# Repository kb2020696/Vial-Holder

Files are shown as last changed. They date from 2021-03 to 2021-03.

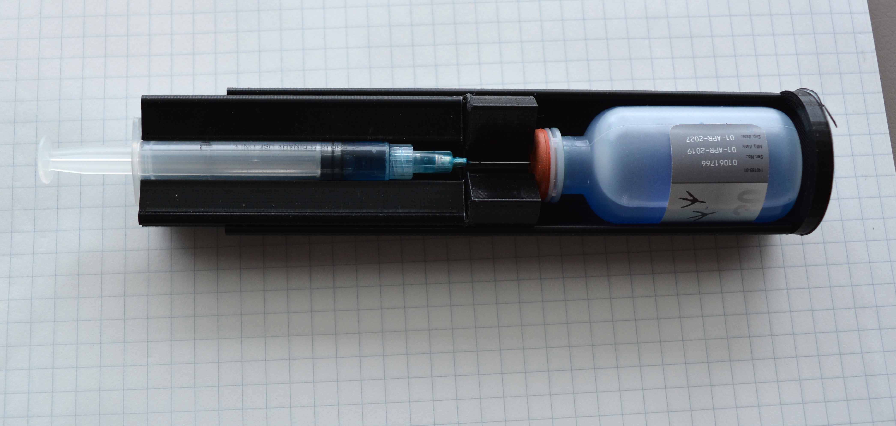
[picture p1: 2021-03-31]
vial holder mod.jpg

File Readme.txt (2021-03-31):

IMPORTANT  - READ THIS FIRST

These files are copyright of LM Designs and may be freely distributed to, and the devices manufactured by, any person who agrees to the following conditions:
1. That any device produced is given freely to any medical professional that requires it with the exception that private individuals may ask for a small charge to cover the actual cost of the materials used.
2. Should any profit be made from the manufacture that it be donated to a charity that supports the families of front line personnel of any type. 

The files provided are AMF (Additive Manufacturing Format) and FCStd (FreeCAD) that enable the device to be printed on any 3D printer after conversion to machine specific code by a suitable slicer such as CURA or the derivative provided by the machine manufacturer.

Since it is likely that the specific dimensions of the device will not be suitable for all situations the actual CAD drawings are made available so that individuals and/or organisations may adapt it to their purposes. In this case the same conditions apply that this is not for profit and any money generated be donated to charity. The original files and the AMF files were generated using FreeCAD. Anyone using these is encouraged to support the organisation (www.freecadweb.org) by making a donation.

THESE FILES ARE PROVIDED BY THE COPYRIGHT HOLDERS "AS IS" AND ANY EXPRESS OR IMPLIED WARRANTIES, INCLUDING, BUT NOT LIMITED TO, THE IMPLIED WARRANTIES OF MERCHANTABILITY AND FITNESS FOR A PARTICULAR PURPOSE ARE DISCLAIMED. IN NO EVENT SHALL THE COPYRIGHT HOLDER OR CONTRIBUTORS BE LIABLE FOR ANY DIRECT, INDIRECT, INCIDENTAL, SPECIAL, EXEMPLARY, OR CONSEQUENTIAL DAMAGES (INCLUDING, BUT NOT LIMITED TO, PROCUREMENT OF SUBSTITUTE GOODS OR SERVICES; LOSS OF USE, DATA, OR PROFITS; OR BUSINESS INTERRUPTION) HOWEVER CAUSED AND ON ANY THEORY OF LIABILITY, WHETHER IN CONTRACT, STRICT LIABILITY, OR TORT (INCLUDING NEGLIGENCE OR OTHERWISE) ARISING IN ANY WAY OUT OF THE USE OF THIS SOFTWARE, EVEN IF ADVISED OF THE POSSIBILITY OF SUCH DAMAGE.

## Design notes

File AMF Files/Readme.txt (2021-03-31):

IMPORTANT  - READ THIS FIRST

These files are copyright of LM Designs and may be freely distributed to, and the devices manufactured by, any person who agrees to the following conditions:
1. That any device produced is given freely to any medical professional that requires it with the exception that private individuals may ask for a small charge to cover the actual cost of the materials used.
2. Should any profit be made from the manufacture that it be donated to a charity that supports the families of front line personnel of any type. 

The files provided are AMF (Additive Manufacturing Format) that enable the device to be printed on any 3D printer after conversion to machine specific code by a suitable slicer such as CURA or the derivative provided by the machine manufacturer.

Since it is likely that the specific dimensions of the device will not be suitable for all situations the actual CAD drawings are be made available so that individuals and/or organisations may adapt it to their purposes. In this case the same conditions apply that this is not for profit and any money generated be donated to charity. The original files and the AMF files were generated using FreeCAD. Anyone using these is encouraged to support the organisation (www.freecadweb.org) by making a donation.

THESE FILES ARE PROVIDED BY THE COPYRIGHT HOLDERS "AS IS" AND ANY EXPRESS OR IMPLIED WARRANTIES, INCLUDING, BUT NOT LIMITED TO, THE IMPLIED WARRANTIES OF MERCHANTABILITY AND FITNESS FOR A PARTICULAR PURPOSE ARE DISCLAIMED. IN NO EVENT SHALL THE COPYRIGHT HOLDER OR CONTRIBUTORS BE LIABLE FOR ANY DIRECT, INDIRECT, INCIDENTAL, SPECIAL, EXEMPLARY, OR CONSEQUENTIAL DAMAGES (INCLUDING, BUT NOT LIMITED TO, PROCUREMENT OF SUBSTITUTE GOODS OR SERVICES; LOSS OF USE, DATA, OR PROFITS; OR BUSINESS INTERRUPTION) HOWEVER CAUSED AND ON ANY THEORY OF LIABILITY, WHETHER IN CONTRACT, STRICT LIABILITY, OR TORT (INCLUDING NEGLIGENCE OR OTHERWISE) ARISING IN ANY WAY OUT OF THE USE OF THIS SOFTWARE, EVEN IF ADVISED OF THE POSSIBILITY OF SUCH DAMAGE.  

Each part of the 8 parts of this device will automatically be printed with the part number. 
The design is intended for use with 3ml or 1ml syringes and vials of 22mm diameter or larger.
The design is easy to modify to use different syringes, vials and needle types with access to the original CAD files. 

Suggested printing instructions

1. This is optimised to print on an extrusion printer. Alterations may be necessary to print on a resin printer.
2. Material:-  This is easiest to print using PLA. The colour of the material is up to the printer or the final user.
3. Print quality:- Since this is intended to be multi-use but essentially disposable if enough are available. The print quality may be lowered to improve printing speed.
4. Slicer settings:- Using PLA on a non glass bed all the parts can be printed wihout brims, platforms or supports. The body, slider and reducer may require a brim depending on the bed and/or machine. All the other parts can be printed without adhesion brims or platforms or supports. Using a glass bed the body, slider and reducer  will require a brim.
5. The following slicer settings are suggested:  Wall thickness 1.5 to 2mm. Interior fill –default (usually 15%) for all parts except the body (#001) and the reducer (#008). These two items are very thin and require a 100% fill. You will require to change the fill % in the advanced or expert settings in the slicer to do this.

Files provided

There are 10 files provided in ZIP file.
Download the ZIP file and extract the files. 

Readme.txt – Contains these instructions
Details.pdf – Contains a detailed description and diagram of the parts. It also gives instruction of how to use the device.

The remaining files are in Additive Manufacturing Format (AMF) to make the 3D printing process machine and slicer independent.
The AMF files:-
Body -001 – main body
Slider -002 – slide section
Spacer -003 to Spacer -006 – Spacer parts of different thicknesses
Pad -007  - Vial location pad – specific to 22mm diameter vial
Reducer -008 – Reducer sleeve to allow the device to be used with 1ml syringes.

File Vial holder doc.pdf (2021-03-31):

Vial holder – functional description

This item consists of 8 separate parts that are assembled to form a complete unit. There is no contact between any part of the unit and the vial contents. Nor should it contact the syringe needles if correctly used. (See the attached diagram).

Part#001 – Outer body. Consists of a platform with a recess to locate a vial and the outer body that holds all the remaining parts in place. The maximum size of vial that can be used is 32mm. Smaller vials can be used with the addition of the vial pad (Part #007)which fits into the main body and is designed to ensure that the vial is centered down the axis of the holder.
Part #002 – Slider. This locates in the main body and is retained in place by protrusions on the body that fit into recesses in the slider. The slider has a longitudinal recess that locates the syringe. The maximum size of syringe that can be used is 3 ml. This is controlled by the size of the recess. With the addition of a reducer sleeve (Part #008) the size of syringe may be reduced.
Parts #003 to #006 – Spacers. These are used in combination to adjust the distance from the outer end of the slider to the cap of the vial being used. In this way the length of needle protruding from the final spacer can be controlled. The ideal is that the needle protrudes far enough only to pierce through the vial cap making removal of the entire contents of the vial simpler.
Part #007 – Vial pad. This item fits inside the main body. Its purpose is to make the center line of the vial line up exactly with the axis of the holder. The thickness of this item controls the exact position of the vial and can be changed by design without affecting the function of the holder.
Part #008 – Reducer sleeve. This reduces the size of the syringe recess to accommodate 1 ml syringe. The internal dimension of this can be changed by design.

How to use this item
This is intended to be held in the hand with the vial at the upper end during normal use.

Section 1 Basic description
1. Ensure that all the parts of the unit are present (see the attached diagram) These are:-
a. Outer body - #001
b. Syringe holder section - #002
c. Spacer parts 3mm #003, 6mm #004, 12mm #005, 18 mm #006
d. Vial pad – #007
e. Reducer sleeve - #008
2. Check that the vial fits into the vial pad. The pad provided is for a standard vial of the type used for a 22mm vial. The device can be used without the pad if necessary.
3. Insert the vial pad into the outer body and slide to the blank end. This is intentionally a tight fit.
4. Take a syringe/needle combination of the type intended to be used for the reconstitution/ dispensing /injections of the vaccine.
5. Slide the assembled syringe into the holder until the finger wings rest on the end of the holder.
6. Remove the needle cover from the syringe and from the side place it into the slot in the syringe holder section.
The following steps (7 through 11) to determine the size of the spacer block need to be done only once assuming the same syringe needle combination is used for all injections.
7. Carefully select which of the spacers will give about 1/4” of needle exposure when placed in contact with the holder. This can be done by inserting the spacer into the outer body of the main assembly from the end. It is retained by the edges of the body.
8. Slide the syringe holder into the body until the spacer contacts the vial pad. At this point the length of the needle protruding from the spacer can be judged. The intention is to have 3/16” to 1/4” of the needle tip exposed. The length of the spacer or a combination of the spacers can used used to get the correct needle tip exposure.
9. Check that the needle is located along the center line of the holder unit. This is to ensure that the needle goes through the center of the vial stopper which is the thinnest part.
10. Slide the syringe holder combination away from the end of the body section until the outer end of the slider is flush with the end of the body.
11. Slide the syringe back in the holder until the needle tip is about 1/2” inside the syringe holder recess.
12. Drop the needle cover into the syringe recess.
13. Slide the syringe forward carefully until the needle is inside the cover.
14. Remove the syringe from the recess and ensure that the needle cover is correctly fitted. Assuming that aseptic precautions have been observed this syringe may be used to reconstitute the vaccine.
15. Remove the crimp from a vial of vaccine and place the vial onto the vial pad.
16. Slide the syringe holder slider section in until the vial is held in place by the spacer block.
17. The holder is now ready for use.

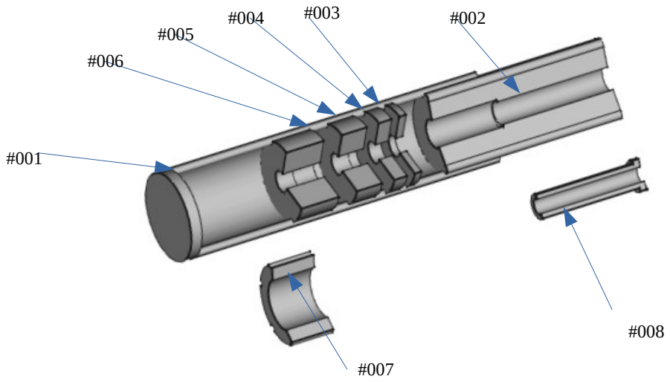
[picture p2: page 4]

#001

#002 #003 #004

#005

#006

#007

#008

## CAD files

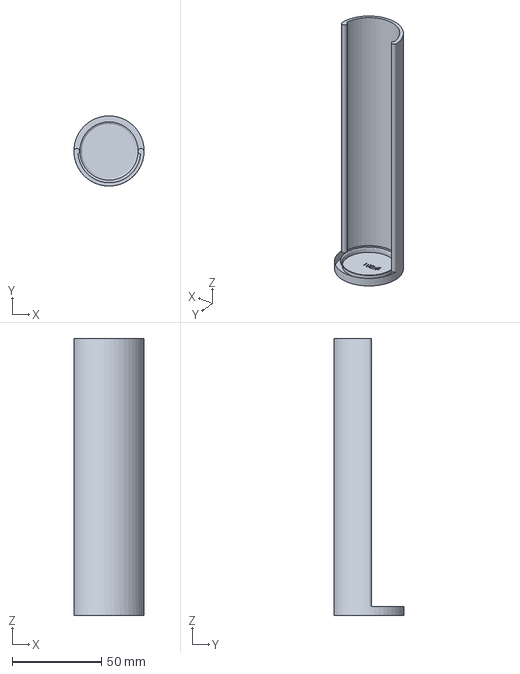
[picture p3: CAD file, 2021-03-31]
AMF Files/Body -001.amf
39.3 x 39.3 x 155.0 mm

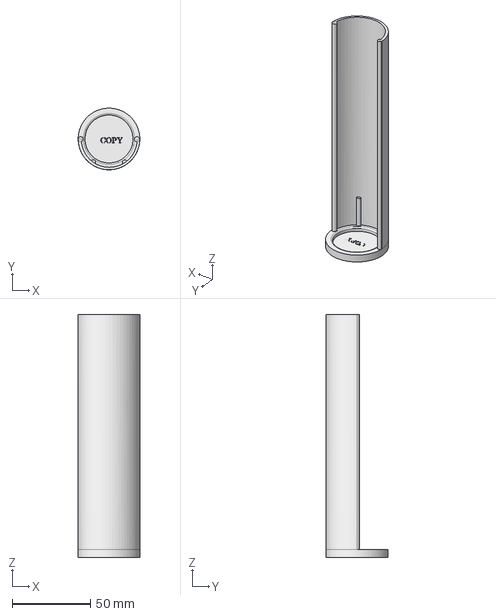
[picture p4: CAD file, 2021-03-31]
CAD Files/Body -copy.FCStd
39.3 x 39.3 x 155.0 mm

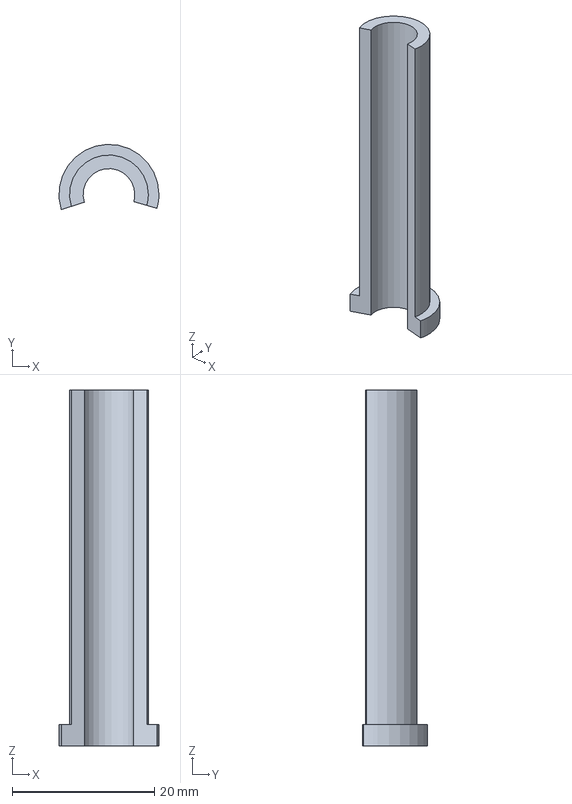
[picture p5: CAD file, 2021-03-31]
AMF Files/Reducer - 008.amf
14.0 x 9.16 x 50.0 mm

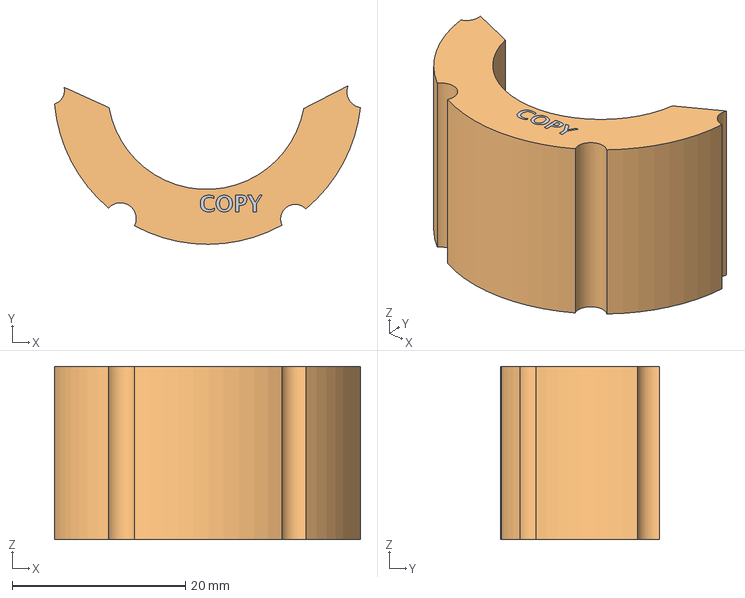
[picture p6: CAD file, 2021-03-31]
CAD Files/Pad -copy.FCStd
35.3 x 18.3 x 20.0 mm
Vial pad 22mm

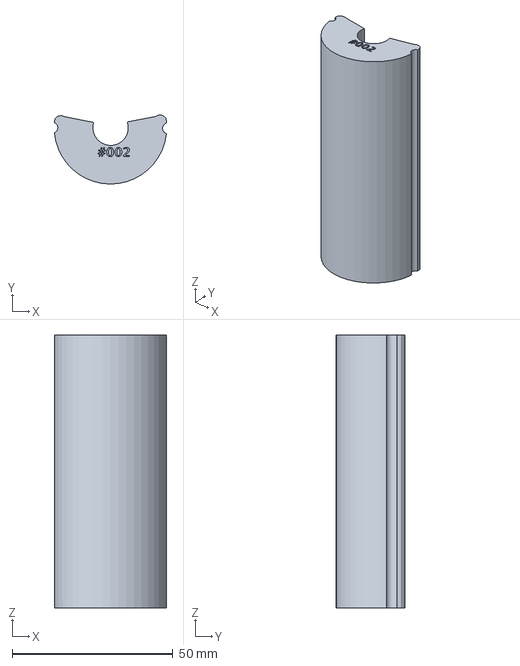
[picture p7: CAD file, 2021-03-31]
AMF Files/Slider -002.amf
34.9 x 21.5 x 85.0 mm

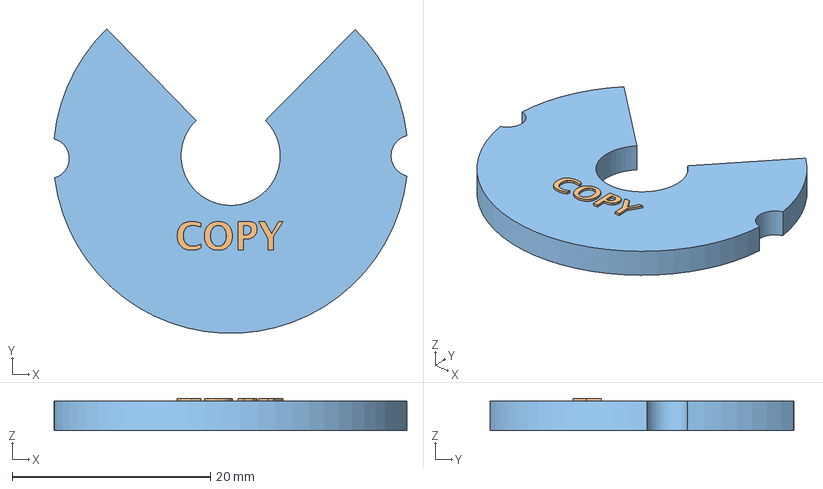
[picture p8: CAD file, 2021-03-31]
CAD Files/Spacer 3-copy.FCStd
35.6 x 30.7 x 3.25 mm
Spacer 3mm

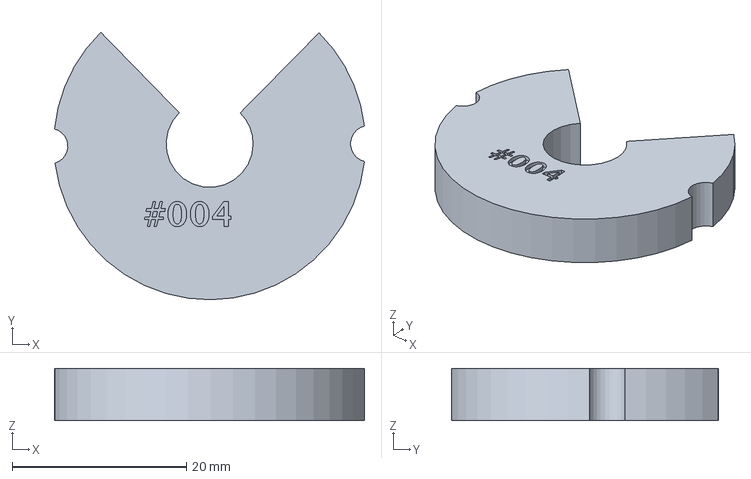
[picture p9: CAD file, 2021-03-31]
AMF Files/Spacer -004.amf
35.6 x 30.7 x 6.00 mm

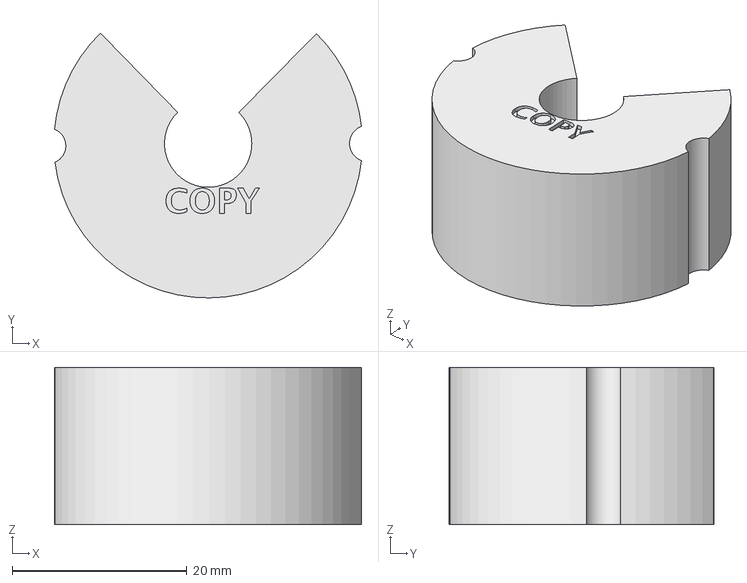
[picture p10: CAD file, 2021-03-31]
CAD Files/Spacer 18 -copy.FCStd
35.2 x 30.3 x 18.0 mm

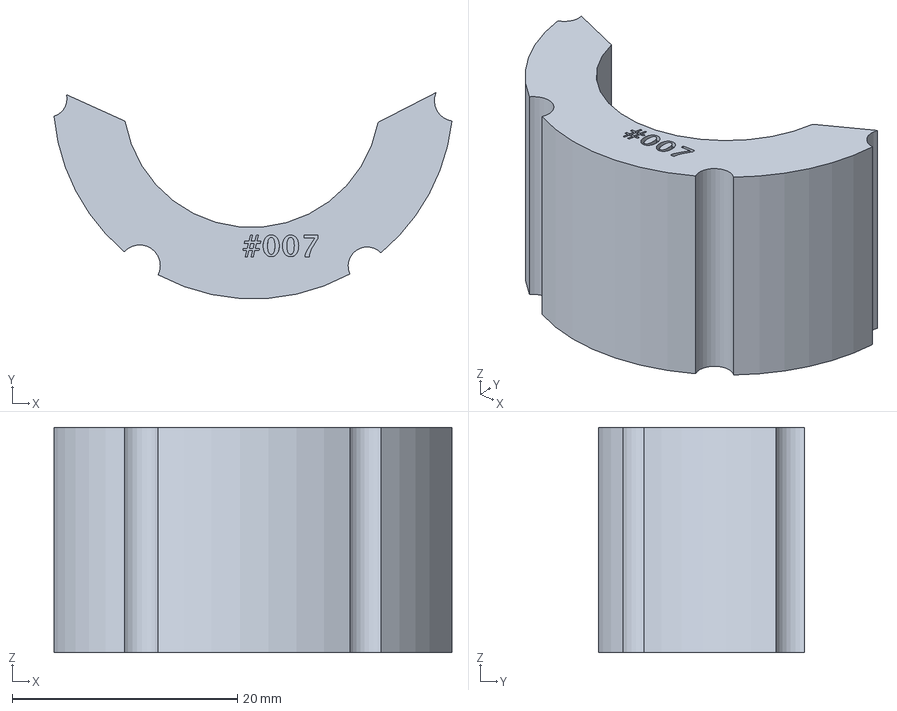
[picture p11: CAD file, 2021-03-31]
AMF Files/Pad -007.amf
35.3 x 18.3 x 20.0 mm

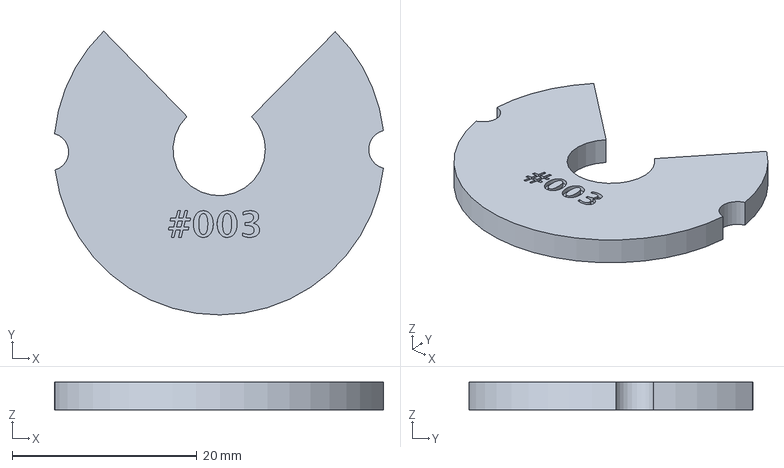
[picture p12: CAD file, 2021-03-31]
AMF Files/Spacer -003.amf
35.6 x 30.7 x 3.00 mm

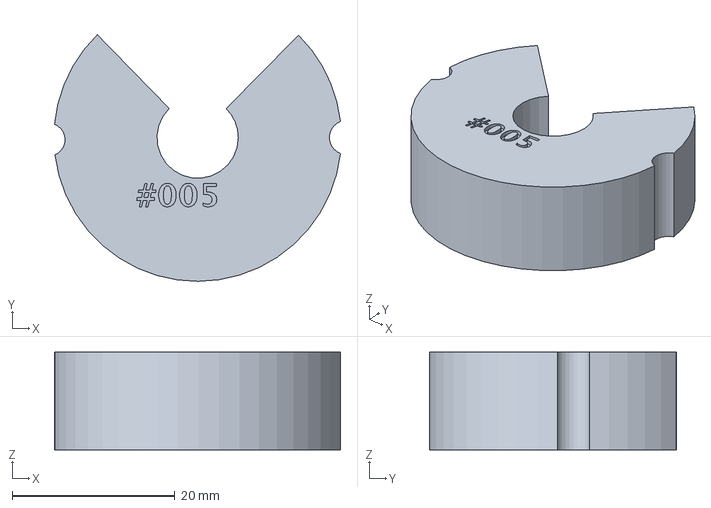
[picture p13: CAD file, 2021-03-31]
AMF Files/Spacer -005.amf
35.2 x 30.3 x 12.0 mm

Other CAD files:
CAD Files/Reducer -copy.FCStd
CAD Files/Spacer 6 -copy.FCStd
CAD Files/Slider -copy.FCStd
AMF Files/Spacer -006.amf
CAD Files/Spacer 12 -copy.FCStd
